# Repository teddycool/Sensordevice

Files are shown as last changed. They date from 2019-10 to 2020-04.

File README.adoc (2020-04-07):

# Sensordevice

A simple generic circuit with example software for a battery powered ESP8266-07.
The circuit can handle one-wire, DHTs and all kinds of I2C sensors. It has capabillities to measures the status of the battery to know  when charging or replacement is needed. The hardware has all pull-ups and pull-downs needed for the different interfaces as well as an onewire tempsensor and an i2c HSM circuit. 

# The Hardware:

The device hardware comes in two flavours:

HW7.1 (left): Powered by 1 1500mAh LiPo and have a built-in charger. Perfect for sensors where charging now and then is an option. The circuitboard is optimised for a FB-29 box

HW8.2 (right): Powered by 3 AAA alkaline batteries. Perfect for sensors that should have a long life-time without battery change and measures rather seldom. The circuitboard is optimised for a FB-29 box.

Since everything will fit i a small enclosure and can be used without any external power supply for long a time, it is well suited for different small sensors or IoT devices. 

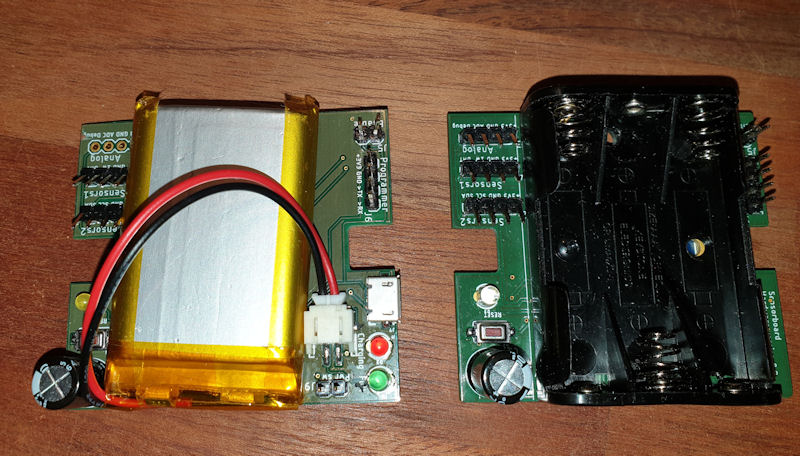
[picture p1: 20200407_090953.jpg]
Hardware version 7 and 8


Hardware 7 and 8.

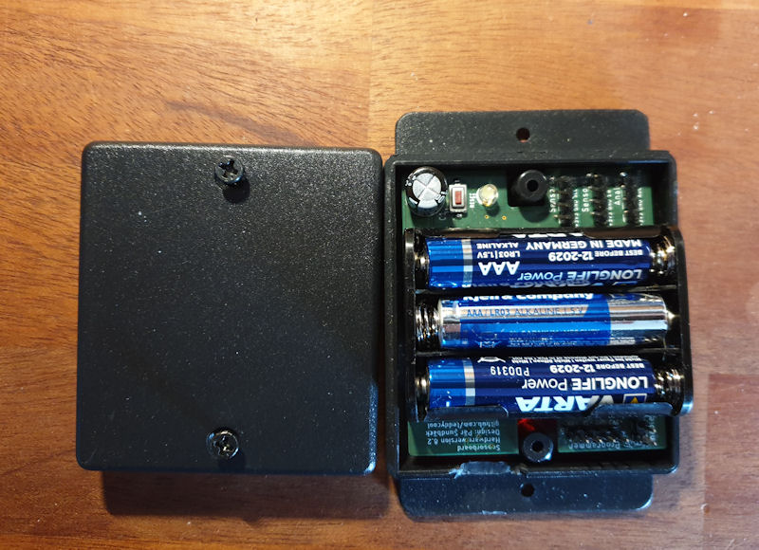
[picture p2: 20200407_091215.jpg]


Hardware 8 in a FB-29 box

There is a also a start for HW9 wich is intended for a power-supply using one AA battery and a 'booster' for ultra low losses. It's a work in (slow) progress so far...

# Software:
Example of software for a device using 2 one-wire temperature gauges and sends information to backend each hour.

## Backend:
Example of html, php, json and sql needed to create some charts with the data.
Data is inserted in a database table using a simple php script, extracted and mangled to json in an other php script and drawn with google chart javascript in the html file.

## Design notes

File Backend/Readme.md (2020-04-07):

This directory contains example of how to use the data from the sensors in a graph with google chart.
The *.html files creates and shows the graphs and the *.php files creates the json data used by the graph.

Since some of the graphs uses combined values from severeal sensors and the sensors don't read the information 
at the same time, I create avarge-values of the readings for each hour before creating the actual json.

The CreateTable.sql creates the needed table structure for using the sql and this is also the structured 
used in the C code of the sensor software.

The view_data.php dumps all data for the las hour to a webpage for debugging purposes.

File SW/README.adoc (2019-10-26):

This directory contains software as an example for how to use the sensorboards.
All version of the hardware can use this software. 
I use Microsoft Visual Studio Code with plattformiIO extentions as developing environment.

There is a general main.cpp used by all boxes.

For each sensor-box I have a .cpp and a .h file with settings for that box' sensors and wifi. Each box sends data to the backend, identifying itself as a device-id and a box name. Each of the sensors data instances are sent as their own backend call and ends up in a database table. The backend can then create tables of data to visualize in a graph or for other purposes. Example graphs and data-mangling can be found in the backend directory of this project. The backend directory also contains details for the database table.

TODO: Create a key/cert to send in the url that is checked before insert into the database.

TODO: Set up a proper build pipe-line for each sensorbox instance. Now I copy and rename files...

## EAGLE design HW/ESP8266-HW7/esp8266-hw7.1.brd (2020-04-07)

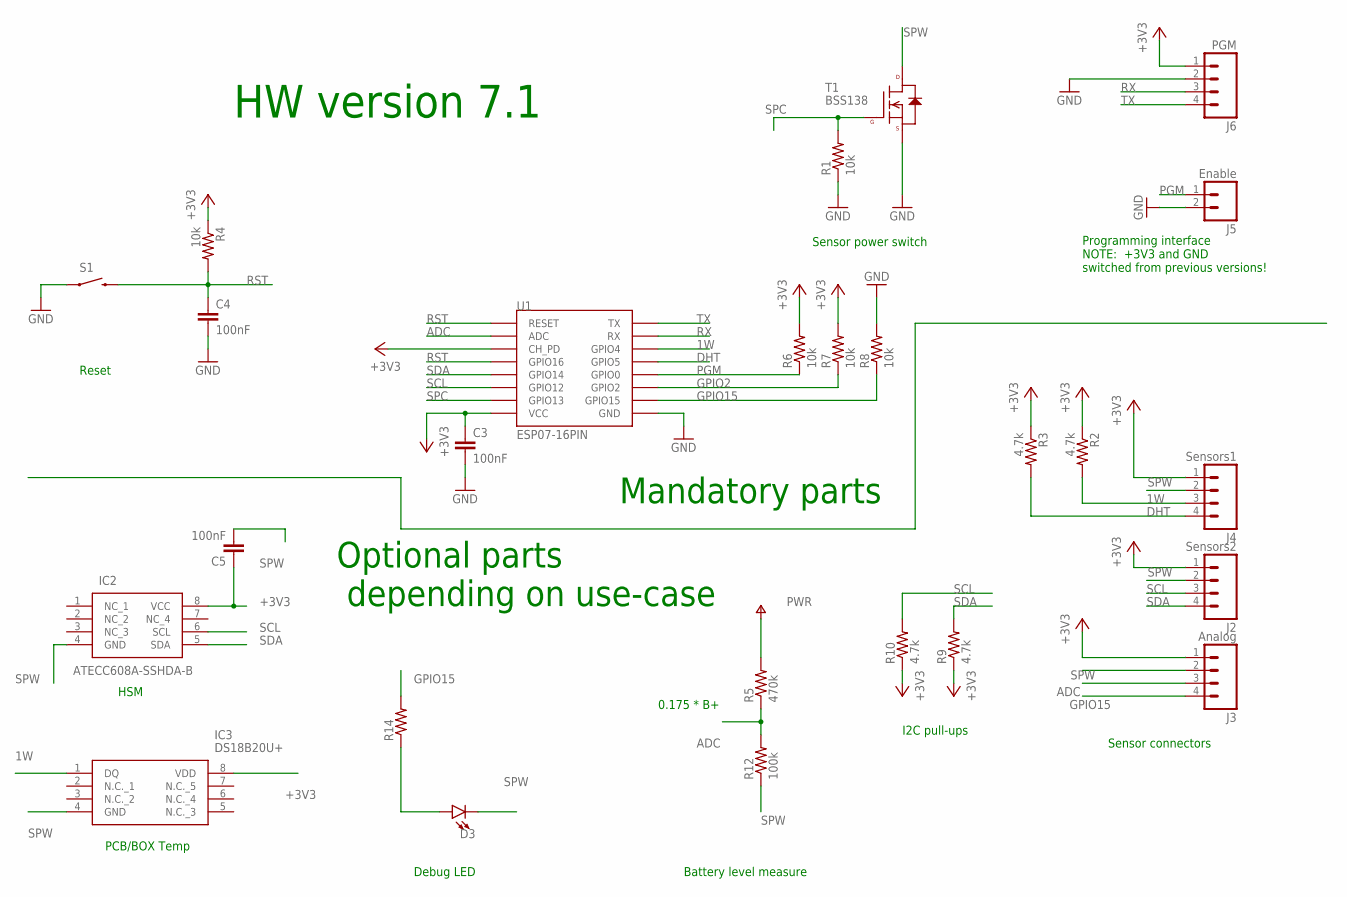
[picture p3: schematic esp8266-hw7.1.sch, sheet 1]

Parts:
C3, C4, C5: 100nF; 0805
D3: LED3MM; LED_3MM
IC2: ATECC608A-SSHDA-B; SOIC127P600X175-8N
IC3: DS18B20U+; SOP65P490X110-8N
J2: Sensors2; 1X04
J3: Analog; 1X04
J4: Sensors1; 1X04
J5: Enable; 1X02
J6: PGM; 1X04
R1, R4, R6, R7, R8: 10k; 0805
R2, R3, R9, R10: 4.7k; 0805
R5: 470k; 0805
R12: 100k; 0805
R14: 470; 0805
S1: RESET; TACTILE-SWITCH-1101NE
T1: BSS138; SOT23-3
U1: ESP07-16PIN

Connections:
1W: IC3.1 (DQ), J4.3, R2.2, U1.GPIO4
+3V3: C3.1, C5.1, IC2.8 (VCC), IC3.8 (VDD), J2.1, J3.1, J4.1, J6.1, R2.1, R3.1, R4.1, R6.2, R7.2, R9.1, R10.1, U1.CH_PD, U1.VCC; also elsewhere on the board
ADC: J3.3, R5.1, R12.2, U1.ADC
DHT: J4.4, R3.2, U1.GPIO5
GND: C3.2, C4.2, J5.2, J6.2, R1.1, R8.2, S1.1, T1.2 (S), U1.GND; also elsewhere on the board
GPIO2: R7.1, U1.GPIO2
GPIO15: J3.4, R8.1, R14.2, U1.GPIO15
unnamed: D3.A, R14.1
PGM: J5.1, R6.1, U1.GPIO0
PWR: R5.2; also elsewhere on the board
RST: C4.1, R4.2, S1.2, U1.GPIO16, U1.REST (RESET)
RX: J6.3, U1.RX
SCL: IC2.6 (SCL), J2.3, R10.2, U1.GPIO12
SDA: IC2.5 (SDA), J2.4, R9.2, U1.GPIO14
SPC: R1.2, T1.1 (G), U1.GPIO13
SPW: C5.2, D3.K (C), IC2.4 (GND), IC3.4 (GND), J2.2, J3.2, J4.2, R12.1, T1.3 (D)
TX: J6.4, U1.TX

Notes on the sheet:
0.175 * B+
Reset
Debug LED
Battery level measure
Sensor power switch
Sensor connectors
I2C pull-ups
Programming interface NOTE: +3V3 and GND switched from previous versions!
HSM
HW version 7.1
PCB/BOX Temp
Mandatory parts
Optional parts depending on use-case

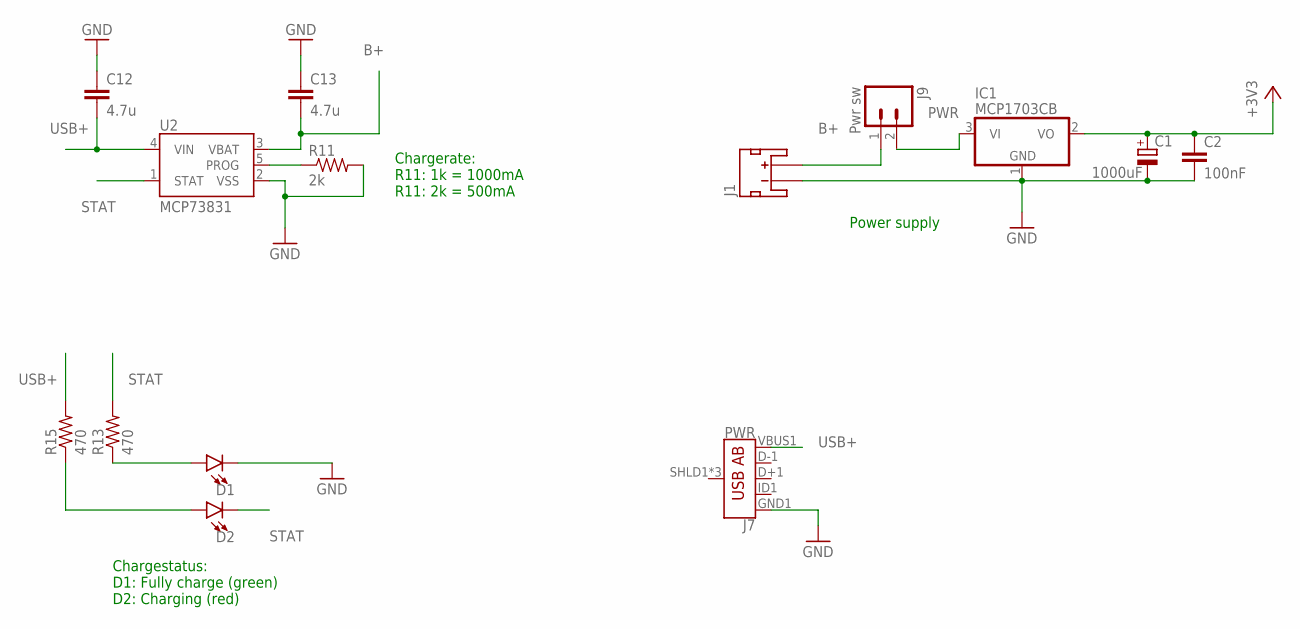
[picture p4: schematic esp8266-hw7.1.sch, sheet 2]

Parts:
C1: 1000uF; E3,5-8
C2: 100nF; 0805
C12, C13: 4.7u; 0805
D1, D2: LED3MM; LED_3MM
IC1: MCP1703CB; SOT23
J1: J1; JST-2-SMD
J7: PWR; USB-AB-MICRO-SMD
J9: Pwr sw; 1X02
R11: 2k; 0805
R13, R15: 470; 0805
U2: MCP73831; SOT23-5

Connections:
+3V3: C1.+, C2.1, IC1.2 (VO); also elsewhere on the board
B+: C13.2, J1.2 (+), J9.1, U2.3 (VBAT)
GND: C1.-, C2.2, C12.1, C13.1, D1.K (C), IC1.1 (GND), J1.1 (-), J7.GND1 (GND), R11.2, U2.2 (VSS); also elsewhere on the board
unnamed: D1.A, R13.1
unnamed: D2.A, R15.1
unnamed: R11.1, U2.5 (PROG)
PWR: IC1.3 (VI), J9.2; also elsewhere on the board
STAT: D2.K (C), R13.2, U2.1 (STAT)
USB+: C12.2, J7.VBUS1 (VBUS), R15.2, U2.4 (VIN)

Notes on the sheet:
Power supply
Chargerate: R11: 1k = 1000mA R11: 2k = 500mA
Chargestatus: D1: Fully charge (green) D2: Charging (red)

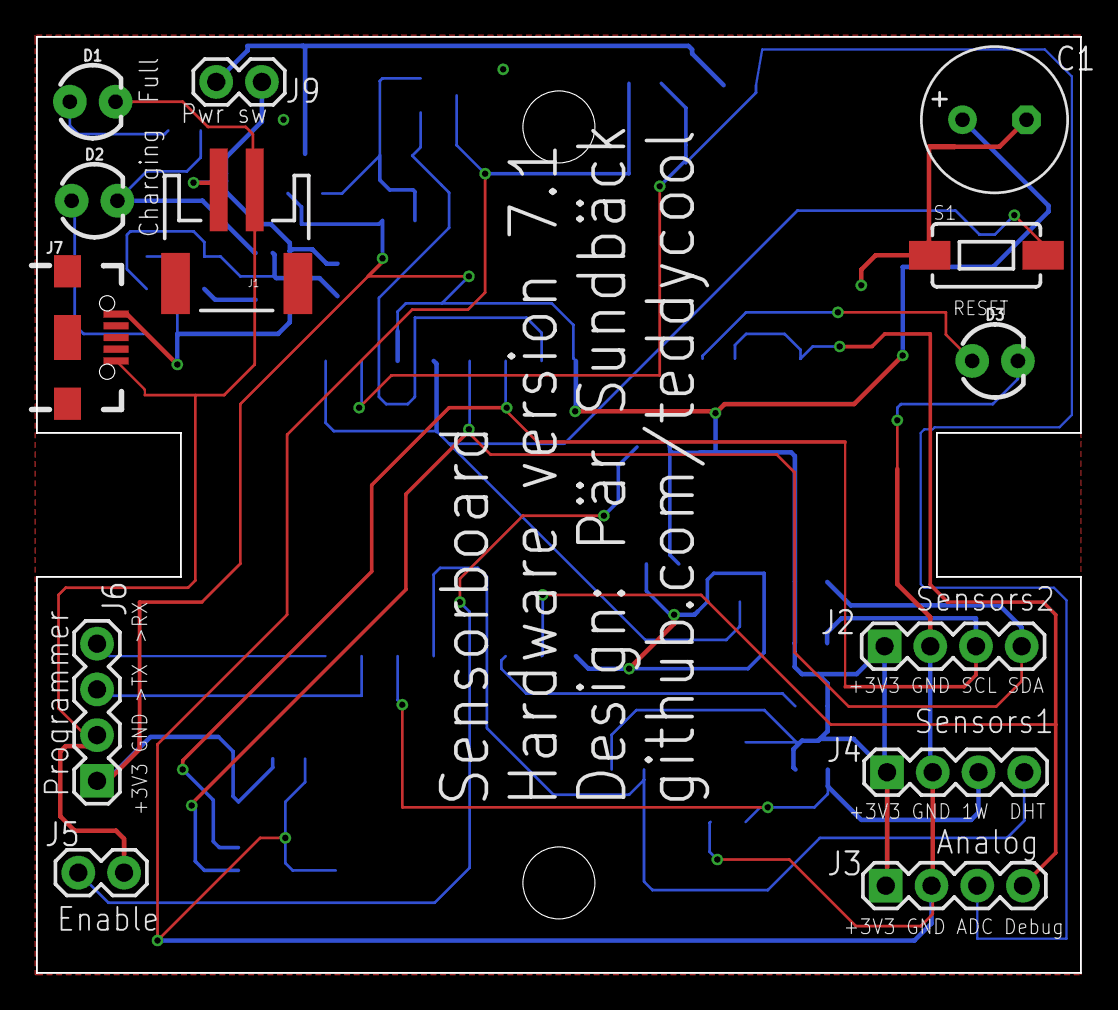
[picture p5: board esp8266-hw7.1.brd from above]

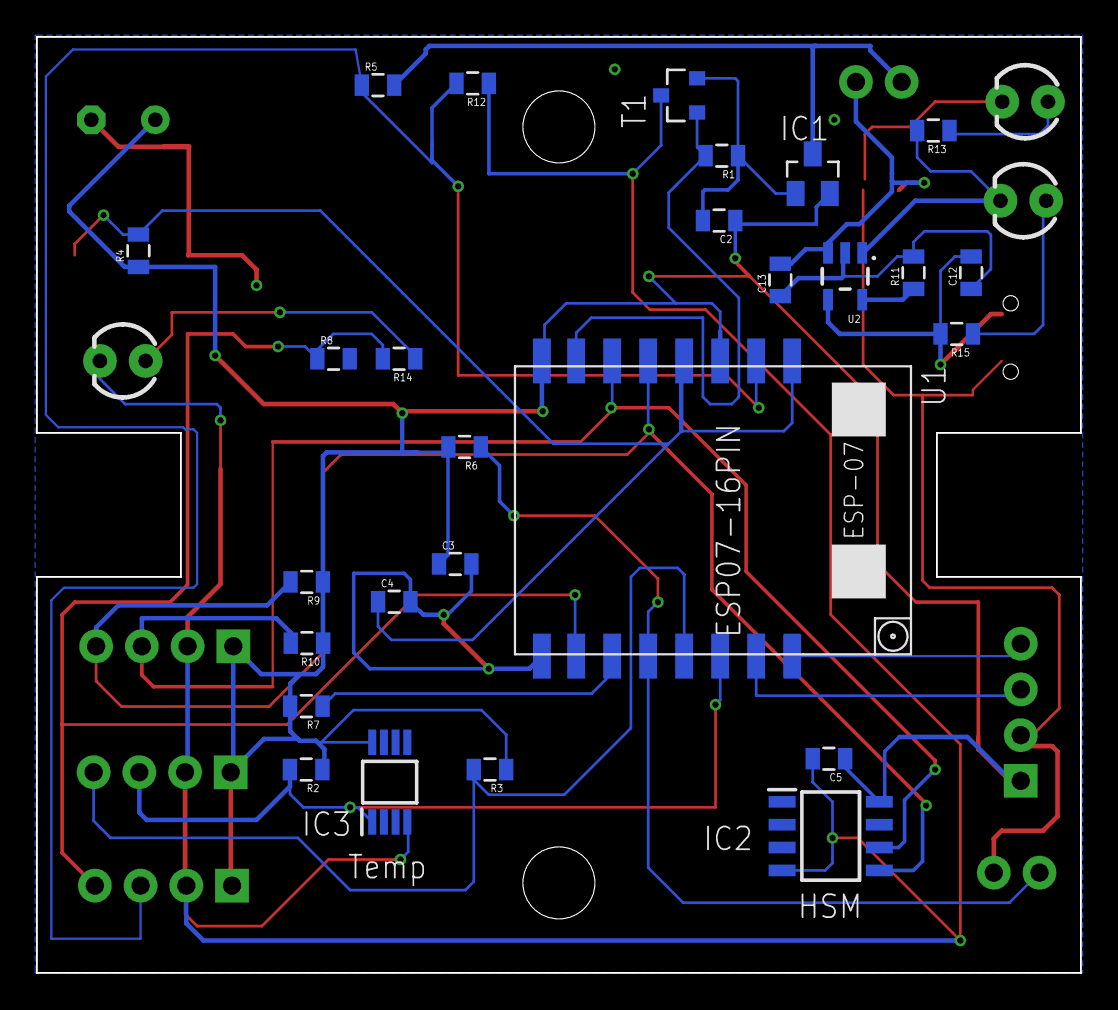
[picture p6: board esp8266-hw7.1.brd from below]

Board: 2 copper layers, 58.0 x 52.0 mm, 40 parts (27 on the bottom side), 23 nets.

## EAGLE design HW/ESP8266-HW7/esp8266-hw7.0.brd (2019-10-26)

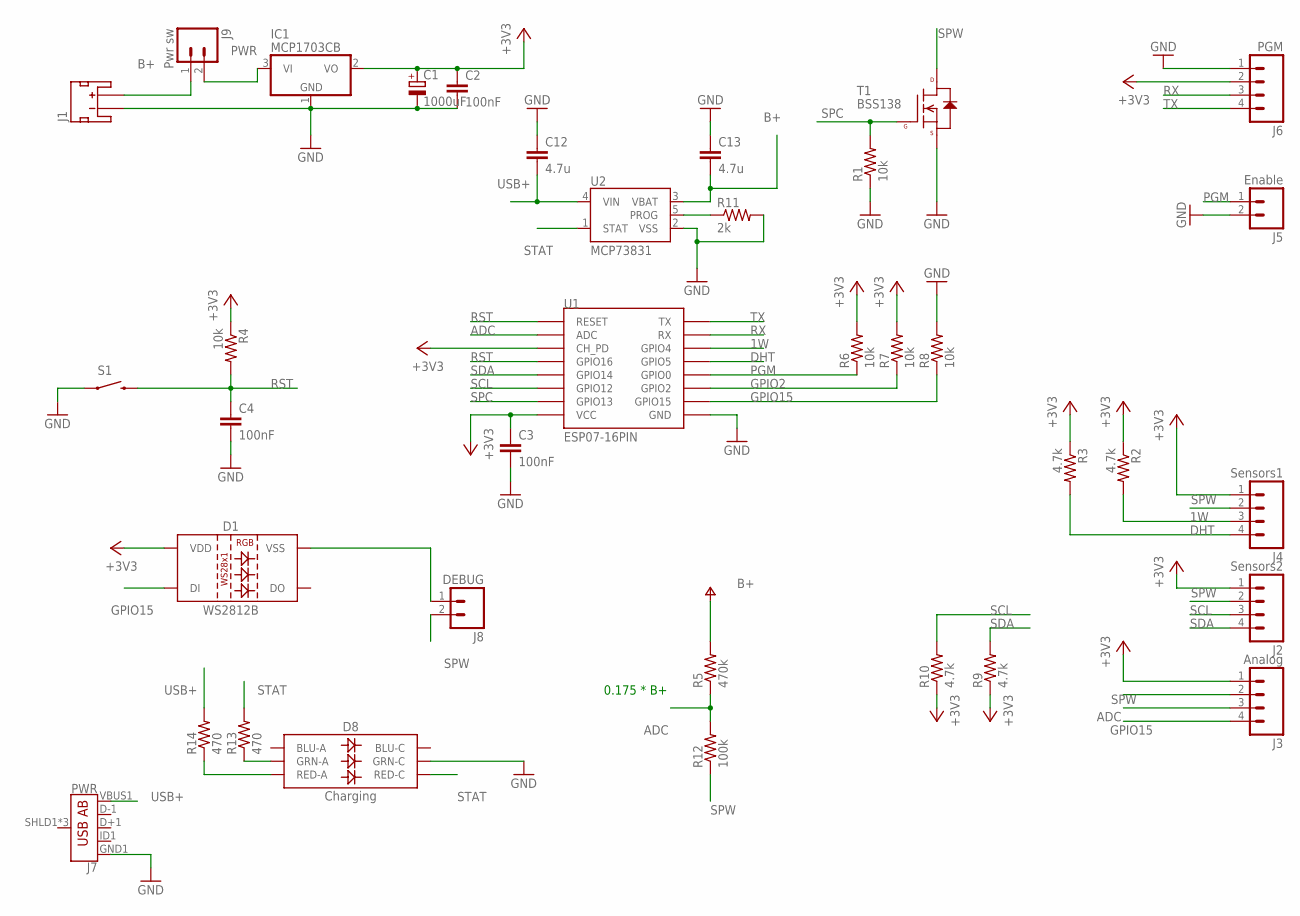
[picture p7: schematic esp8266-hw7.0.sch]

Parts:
C1: 1000uF; E3,5-8
C2, C3, C4: 100nF; 0805
C12, C13: 4.7u; 0805
D1: WS2812B
D8: Charging; LED-TRICOLOR-5050
IC1: MCP1703CB; SOT23
J1: J1; JST-2-SMD
J2: Sensors2; 1X04
J3: Analog; 1X04
J4: Sensors1; 1X04
J5: Enable; 1X02
J6: PGM; 1X04
J7: PWR; USB-AB-MICRO-SMD
J8: DEBUG; 1X02
J9: Pwr sw; 1X02
R1, R4, R6, R7, R8: 10k; 0805
R2, R3, R9, R10: 4.7k; 0805
R5: 470k; 0805
R11: 2k; 0805
R12: 100k; 0805
R13, R14: 470; 0805
S1: RESET; TACTILE-SWITCH-1101NE
T1: BSS138; SOT23-3
U1: ESP07-16PIN
U2: MCP73831; SOT23-5

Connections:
1W: J4.3, R2.2, U1.GPIO4
+3V3: C1.+, C2.1, C3.1, D1.1 (VDD), IC1.2 (VO), J2.1, J3.1, J4.1, J6.2, R2.1, R3.1, R4.1, R6.2, R7.2, R9.1, R10.1, U1.CH_PD, U1.VCC
ADC: J3.3, R5.1, R12.2, U1.ADC
B+: C13.2, J1.2 (+), J9.1, R5.2, U2.3 (VBAT)
DHT: J4.4, R3.2, U1.GPIO5
GND: C1.-, C2.2, C3.2, C4.2, C12.1, C13.1, D8.6 (GRN-C), IC1.1 (GND), J1.1 (-), J5.2, J6.1, J7.GND1 (GND), R1.1, R8.2, R11.2, S1.1, T1.2 (S), U1.GND, U2.2 (VSS)
GPIO2: R7.1, U1.GPIO2
GPIO15: D1.4 (DI), J3.4, R8.1, U1.GPIO15
unnamed: D8.1 (GRN-A), R13.1
unnamed: D1.3 (VSS), J8.1
unnamed: D8.2 (RED-A), R14.1
unnamed: R11.1, U2.5 (PROG)
PGM: J5.1, R6.1, U1.GPIO0
PWR: IC1.3 (VI), J9.2
RST: C4.1, R4.2, S1.2, U1.GPIO16, U1.REST (RESET)
RX: J6.3, U1.RX
SCL: J2.3, R10.2, U1.GPIO12
SDA: J2.4, R9.2, U1.GPIO14
SPC: R1.2, T1.1 (G), U1.GPIO13
SPW: J2.2, J3.2, J4.2, J8.2, R12.1, T1.3 (D)
STAT: D8.5 (RED-C), R13.2, U2.1 (STAT)
TX: J6.4, U1.TX
USB+: C12.2, J7.VBUS1 (VBUS), R14.2, U2.4 (VIN)

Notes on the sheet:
0.175 * B+

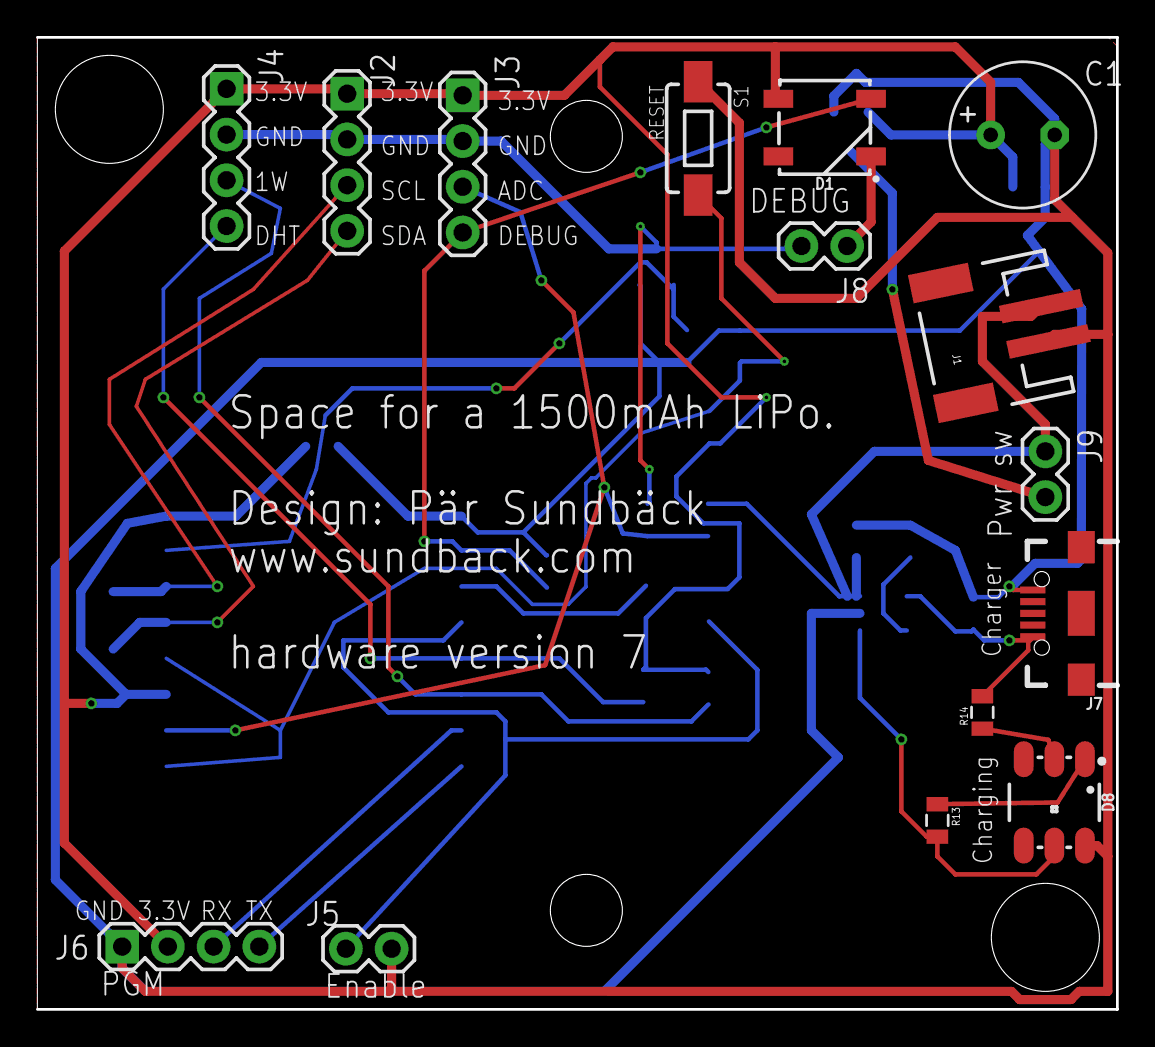
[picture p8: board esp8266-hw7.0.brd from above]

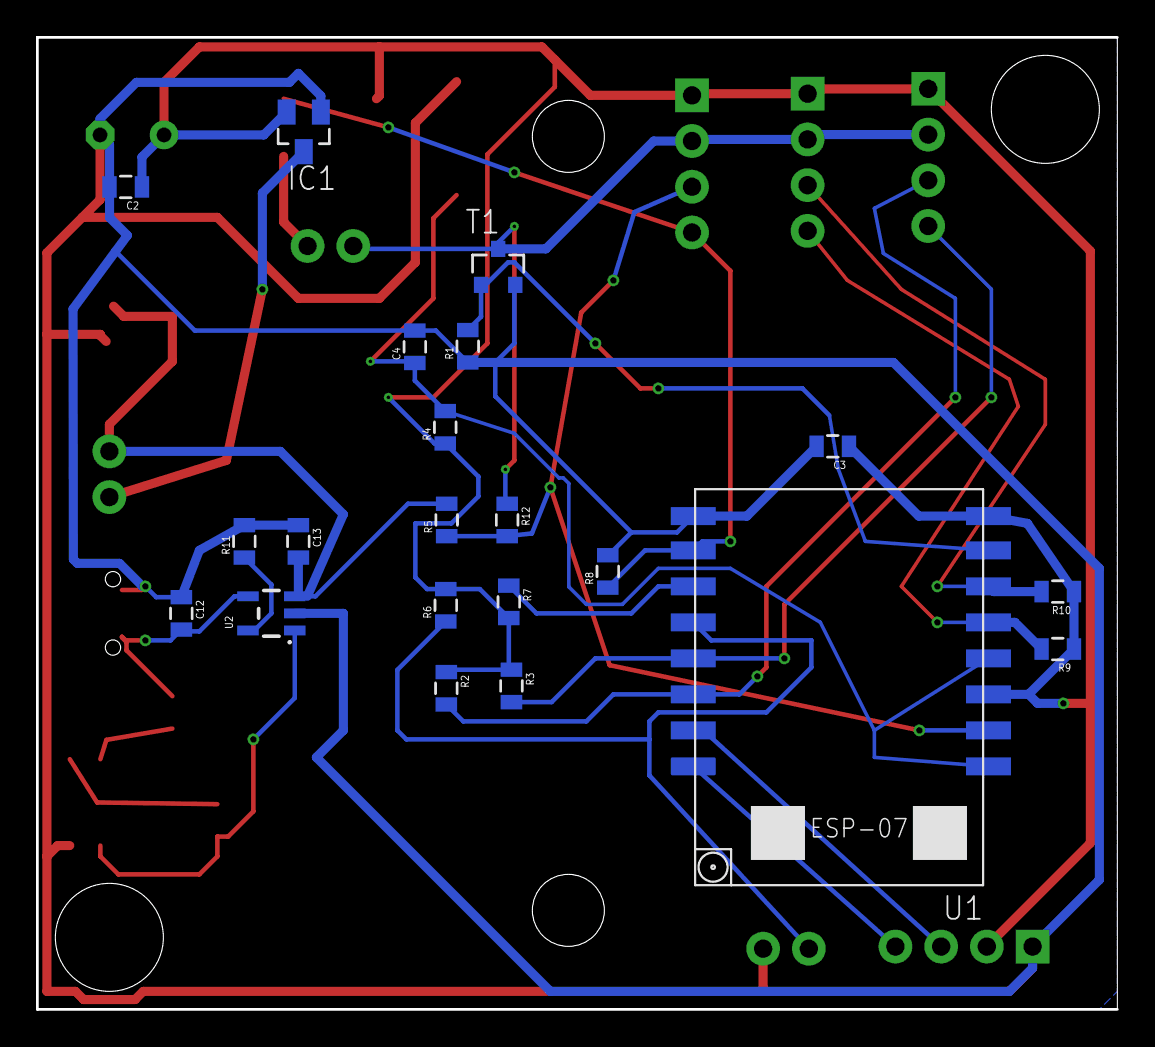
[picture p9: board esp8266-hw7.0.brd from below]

Board: 2 copper layers, 60.0 x 54.0 mm, 36 parts (21 on the bottom side), 23 nets.

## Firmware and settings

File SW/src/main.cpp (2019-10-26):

/*********
 * By teddycool, based on code from randomnerdtutorials (Rui Santos at http://randomnerdtutorials.com)
 * Compatible with ESP sensorboard HW-version > 7.x, www.github.com/teddycool/ for details
 * This file is the main-class, handling wifi connection and basic logic for hw  
 * but also general functions such as reading of battery level
 * 
 * Each box has it's own implementation of settings and sensor-readings imported as the last #include
 * Rename the current config implementation to .cpp, the rest to ._cp or something...
 * Set last include to the correct -h file
 * *********/

// Including the ESP8266 WiFi library

//#include <PubSubClient.h>
#include <Wire.h>
#include <WiFiUdp.h>
#include <WiFiServer.h>
#include <WiFiClientSecure.h>
#include <WiFiClient.h>
#include <ESP8266WiFiType.h>
#include <ESP8266WiFiSTA.h>
#include <ESP8266WiFiScan.h>
#include <ESP8266WiFiMulti.h>
#include <ESP8266WiFiGeneric.h>
#include <DHT.h>
#include <Adafruit_Sensor.h>
#include "av8s1.h"  


WiFiClient espClient;
ADC_MODE(ADC_TOUT);

//Extern defnitions from the actual box implementation files

extern const char* ssid;
extern const char* password;
//extern const float calvalue; 

extern const char* server; 
extern const char* resource; 

extern int32 sleepTimeS;


void setup() {
	
  //Not used since deep-sleep makes a total reset each restart and runs loop() only once each cycle
	
}

void loop() {		


	// Initializing serial port for debugging purposes
	Serial.begin(9600);
	Serial.println("Starting serial");

	bool wificonnected = false;
	int maxtries = 6;
	int tries = 0;
	pinMode(13, OUTPUT);

	// Connecting to WiFi network
	Serial.println();
	Serial.println("Connecting to ");
	Serial.println( ssid);
	WiFi.begin( ssid,  password);
	delay(2000);
	
	//Maximize number of tries...	
	while ((!wificonnected) && (tries <= maxtries)) {
		if (WiFi.status() == WL_CONNECTED) {
			wificonnected = true;
			Serial.println("");
			Serial.println("WiFi connected");
			Serial.println(WiFi.localIP());
			break;
		}
		else {
			Serial.print(".");
			tries = tries + 1;
			delay(1000);
		}
	}

	//Only do reading if connected to wifi, 
	if (wificonnected) {
		int retries = 3;   
		Serial.println("Connecting to: " + String(server)); 
		while(!espClient.connect(server, 80) && (retries-- > 0)) 
		{     
			Serial.print(".");
			delay(500);
		} 

		if(!espClient.connected()) {     
			 Serial.println("Failed to connect, going back to sleep");   
		}
		else { 
			Serial.println("Connected and ready to make measurements....");
			Serial.println("Setting up power to sensors...");
			digitalWrite(13, HIGH);				
			Serial.println("Waiting to stabilize...");
			delay(2000);

			//Sensor readings moved to cpp file for each sensor
			ReadSensors( espClient, server);

			Serial.println("Reading battery voltage on A0...");
			int batterya = analogRead(A0);
			Serial.println(String(batterya));
			float batv = (float(batterya)/1024.0)/0.178; 
			Serial.println(String(batv) + "V");

			espClient.connect(server, 80);
			espClient.print(getPostMsg("bat",String(batv), "V" )); 
			delay(500);
			espClient.connect(server, 80);
			espClient.print(getPostMsg("wifi",String(tries), "counts" )); 
			delay(500);
		}  //end of connected to server

	espClient.stop(); 
	Serial.println();
	Serial.println("Turning off power to pins...");	
	digitalWrite(13, LOW);
	delay(500);	
		
	} //end of connected to wifi

  //ALLWAYS go to sleep again...

  Serial.println("Going to sleep....");
  uint32 micros = (uint32)sleepTimeS*1000000;
  String secs = String(sleepTimeS).c_str();
  Serial.println("Will sleep for " + secs + " seconds...");
  ESP.deepSleep(micros);  //uS!		
}

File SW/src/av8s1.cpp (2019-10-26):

//Main setting file for sensorboard
#include <OneWire.h>
#include <DallasTemperature.h>
#include <WiFiClient.h>
#include "av8s1.h"

#define ONE_WIRE_BUS 5
//Hardware version:
#define hw_version 8
//Client WiFi-settings
#define client_name "av8_s2"

// Measure real voltage level for the batteries and calculate this value for the actual box,
// depending on component exact values, should be around 0.18
// calvalue = (analogvalue/1024.0) / (real voltage)
const float calvalue = 0.178; 

//Backend info for publishing the values
const char* server = "server"; 
const char* resource = "/SensorBoardBackEnd/post_value.php?devid=5&devname=Demo&"; 

//WiFi connection
const char* ssid = "sssid";
const char* password = "key";
int32 sleepTimeS = 3600; //sleptime in seconds, 


//Each post contains one value and should add this to the url-string:
// measm=type&value=value&unit=unit,  i e measm=bat&value=4.6&unit=V

OneWire oneWire(ONE_WIRE_BUS);
DallasTemperature sensors(&oneWire);

DeviceAddress outSensor = {0x28, 0xFF, 0x88, 0xC0, 0xA7, 0x16, 0x05, 0x71}; //  short wire - outside
DeviceAddress foundSensor = {0x28, 0xFF, 0x61, 0x01, 0x00, 0x17, 0x03, 0x7B}; // long wire - inside



//Complete test-url can look like:
// http://server/SensorBoardBackEnd/post_value.php?devid=1&devname=av8_box1&measm=bat&value=4.6&unit=V
String getPostMsg(String pmeasurement, String pvalue, String punit){

	String ppost = "GET " + String(resource) + "&measm=" + pmeasurement +"&value=" + pvalue + 
				"&unit=" + punit +  " HTTP/1.1\r\n" + "Host: " + String(server) + "\r\n"+ "Connection: close\r\n\r\n";

	Serial.println("Created http request:");
	Serial.println(ppost);
	return ppost;
}

//The sensor readings for the box, depending on the sensor used
void ReadSensors(WiFiClient espClient, const char* server){
    sensors.requestTemperatures(); 
    delay(1000);
    if (sensors.isConversionComplete()){
        Serial.println("Conversion complete. Reading and sending data");
        //Read outdoor sensor
        float outtemp = sensors.getTempC(outSensor);
        //Read inside foundation sensor
        float foundtemp = sensors.getTempC(foundSensor);

        espClient.print(getPostMsg("otemp", String(outtemp), "C")); 
        delay(500);

        espClient.connect(server, 80);
        espClient.print(getPostMsg("ftemp",String(foundtemp), "C" )); 
        delay(500);

        }
        else {
            Serial.println("Conversion NOT complete. Dont send any data");
        }
}

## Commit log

2019-10-26 First commit
    New repo, first commit
    [esp8266-hw7.brd, esp8266-hw7.sch, esp8266-hw8.brd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]
2020-04-07 New pcb releases and some updated software
    New (final?) releases of pcbs for version 7 and 8. New test program to run for test of the built hardware.
    [esp8266-hw7.0.brd, esp8266-hw7.0.sch, esp8266-hw7.1.brd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]

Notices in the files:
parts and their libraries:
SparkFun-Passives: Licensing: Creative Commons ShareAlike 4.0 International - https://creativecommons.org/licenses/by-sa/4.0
